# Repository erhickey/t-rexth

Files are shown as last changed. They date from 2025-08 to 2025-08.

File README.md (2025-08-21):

<p align="center">
  t-rexth-logo
</p>

# Thyranathaurus Rexth

Several versions of a split keyboard I created using [Ergogen](https://github.com/ergogen/ergogen).

## [T-Rexth 36 Wired](./t-rexth-36-wired)

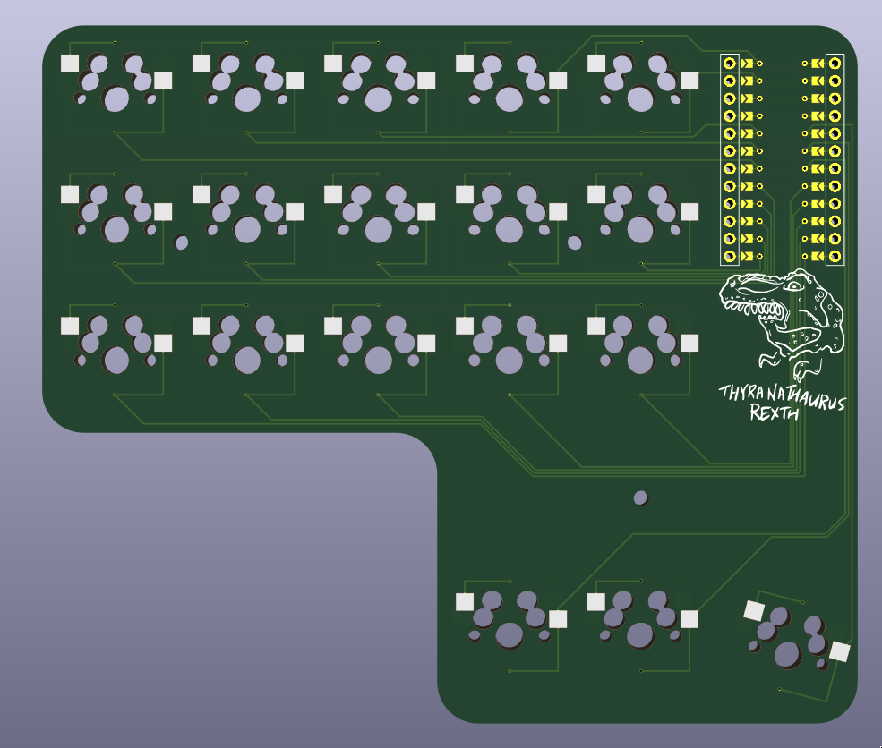
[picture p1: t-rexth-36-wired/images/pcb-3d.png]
t-rexth-36


- 36 keys
- Split keyboard
- Ortholinear
- Wired
- MX switch compatible
- Hot swap sockets

## [T-Rexth 36](./t-rexth-36)

t-rexth-36

- 36 keys
- Split keyboard
- Ortholinear w/columnar stagger
- Wireless
- MX switch compatible
- Hot swap sockets
- Tenting puck compatible

## [T-Rexth 30](./t-rexth-30)

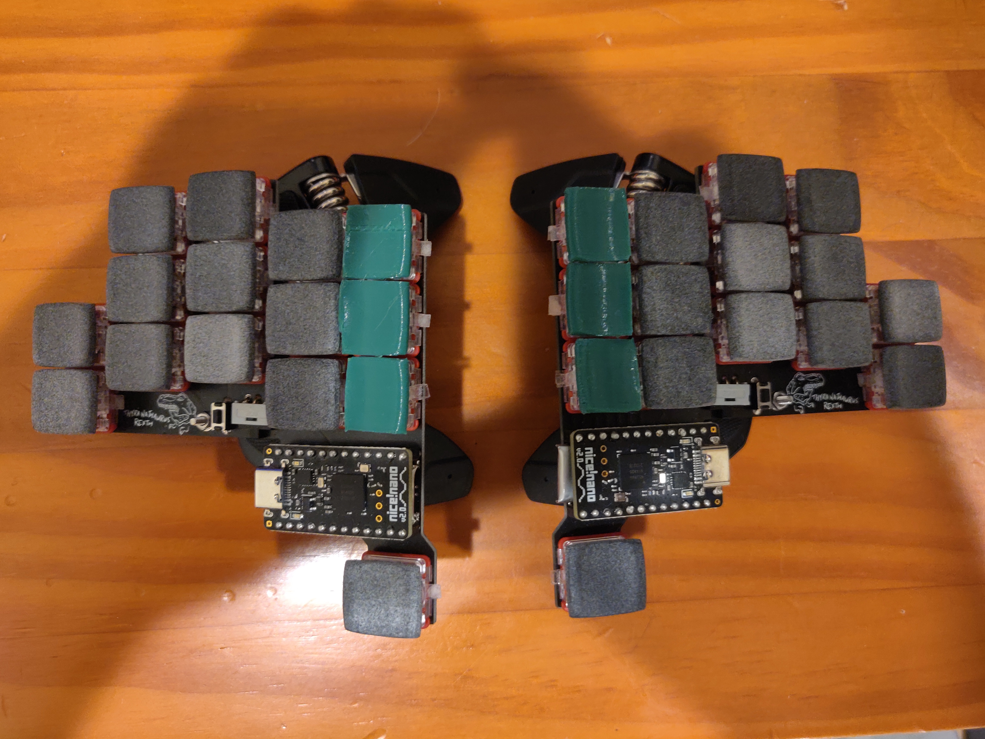
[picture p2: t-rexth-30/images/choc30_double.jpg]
t-rexth-36


- 30 keys
- Split keyboard
- Ortholinear w/columnar stagger
- Wireless
- Choc switch compatible
- Minimal spacing
- Tenting puck compatible

# Credits/Thanks

- Created with [Ergogen](https://github.com/ergogen/ergogen) by [MrZealot](https://zealot.hu/)
- Motivated by [Ben Vallack's videos](https://www.youtube.com/channel/UC4NNPgQ9sOkBjw6GlkgCylg)
- [Guide](https://flatfootfox.com/ergogen-introduction/) by [FlatFootFox](https://flatfootfox.com/)
- Lots of help from members of [Ergogen Discord](https://discord.gg/nbKcAZB)
- Artwork by [Perce](https://madebyperce.com)
- Keycaps by [Pseudoku](https://github.com/pseudoku/PseudoMakeMeKeyCapProfiles)
- Tenting Puck by [lacohe](https://www.thingiverse.com/thing:5336898)

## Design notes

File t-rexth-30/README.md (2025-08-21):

# Thyranathaurus Rexth 30

t-rexth-36

## Notes

This was my first attempt at building a custom keyboard, and has a couple issues:

- Attempting to solder battery wires onto the PCB without shorting your battery can be tricky.
- The spacing between the innermost columns is not wide enough, thus the philadelphia minimalist keycaps [do not fit both columns](./images/choc30_single.jpg).

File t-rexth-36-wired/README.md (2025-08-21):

# Thyranathaurus Rexth

Under construction

## Firmware

[Example zmk configuration](https://github.com/erhickey/keyboards/tree/main/)

## Notes

Uses [infused-kim's](https://github.com/infused-kim) [reversible nice!nano footprint](https://github.com/infused-kim/kb_ergogen_fp/).

## Parts

In addition to the parts below a JST SH 4 pin cable and hotswap sockets are required.

| Type | Part | Details |
|---|---|---|
| Controller | [Adafruit KB2040 - RP2040 Kee Boar Driver](https://octopart.com/search?q=kb2040&currency=USD&specs=0) | [Adafruit](https://learn.adafruit.com/adafruit-kb2040) |
| Machine Pin Sockets | [Mill-Max 801 INTERCONNECT MACHINED PIN SOCKET](https://octopart.com/search?q=801-47-012-10-012000&currency=USD&specs=0) | [Mill-Max](https://www.mill-max.com/products/socket/801-xx-xxx-10-012000) |
| Socket Pins | [Mill-Max 3330 Straight Pin](https://octopart.com/search?q=3330-0-00-15-00-00-03-0&currency=USD&specs=0) | [Mill-Max](https://www.mill-max.com/products/pin/3330) |
| M2x8 Screws | [M2x8 Socket Hex Pan Head Screw](https://www.amazon.com/YXQ-Socket-Machine-Threaded-Knurled/dp/B01EZPNXZO?th=1) | Part Number: MT0502-004 - 3.8mm Head Diameter 2mm Head Height |
| M2 Threaded Insert | [M2 Female Thread Brass Threaded Insert](https://www.amazon.com/dp/B07LBQFNQD?th=1) | 3mm Length x 3.2mm OD |

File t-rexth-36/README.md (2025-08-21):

# Thyranathaurus Rexth 36

t-rexth-36

## Notes

PCB track width and spacing is 0.15mm. Make sure your manufacturer is capable of printing boards with those specs. I used [JLCPCB](https://jlcpcb.com/capabilities/pcb-capabilities).

## Parts

| Type | Part | Manufacturer |
|---|---|---|
| Tactile Button | [C&K PTS636 SP43 LFS](https://www.mouser.com/ProductDetail/CK/PTS636-SP43-LFS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) | [C&K Switches](https://www.ckswitches.com/media/2779/pts636.pdf) |
| Slide Switch | [EAO 09.10290.01](https://www.mouser.com/ProductDetail/EAO/091029001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) | [EAO](https://eao.com) |
| Machine Pin Sockets | [Mill-Max 801 INTERCONNECT MACHINED PIN SOCKET](https://www.mouser.com/ProductDetail/Mill-Max/801-47-012-10-012000?qs=5aG0NVq1C4x40xNvDlnKzg%3D%3D) | [Mill-Max](https://www.mill-max.com/products/socket/801-xx-xxx-10-012000) |
| Socket Pins | [Mill-Max 3330 Straight Pin](https://www.mouser.com/ProductDetail/Mill-Max/3330-0-00-15-00-00-03-0?qs=s8Nb1z4Wn%2FSwJBcI97lmUw%3D%3D) | [Mill-Max](https://www.mill-max.com/products/pin/3330) |
| JST PH 2.0 Connector | [TE 1775469-2](https://www.mouser.com/ProductDetail/TE-Connectivity/1775469-2?qs=fvVej%2FMj3jdYOde%252BssG5lg%3D%3D) | [TE Connectivity](https://www.te.com/usa-en/product-1775469-2.html) |

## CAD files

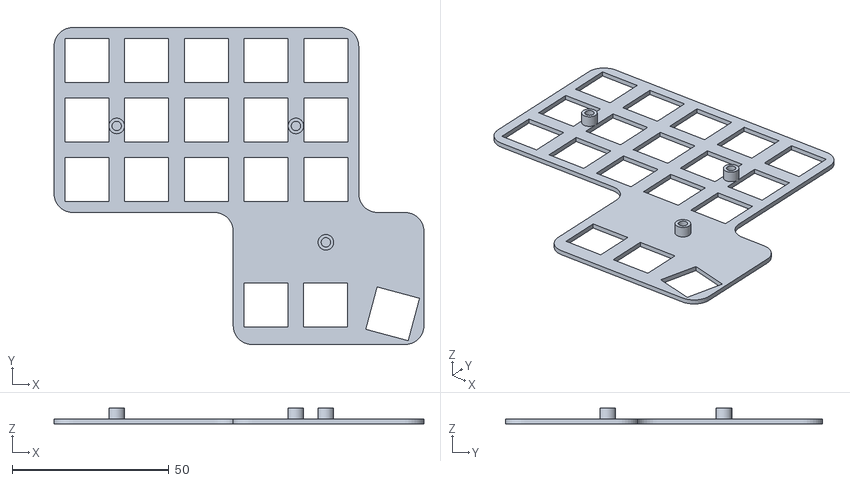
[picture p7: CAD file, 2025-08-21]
t-rexth-36-wired/case/plate_right.stl
118.0 x 101.1 x 5.00

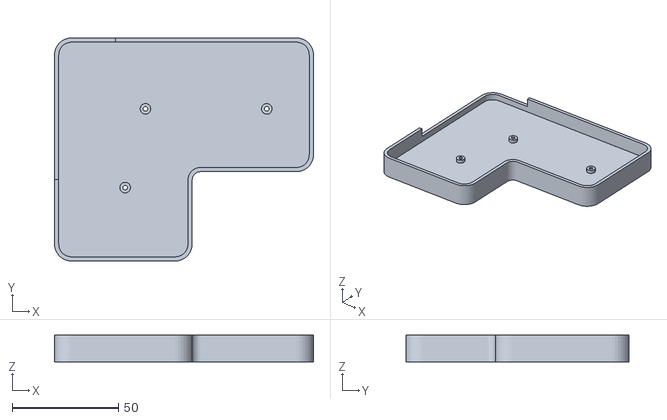
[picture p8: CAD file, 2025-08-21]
t-rexth-36-wired/case/bottom_right.stl
122.0 x 105.1 x 12.6

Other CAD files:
t-rexth-36-wired/case/bottom_left.stl
t-rexth-36-wired/case/plate_left.stl

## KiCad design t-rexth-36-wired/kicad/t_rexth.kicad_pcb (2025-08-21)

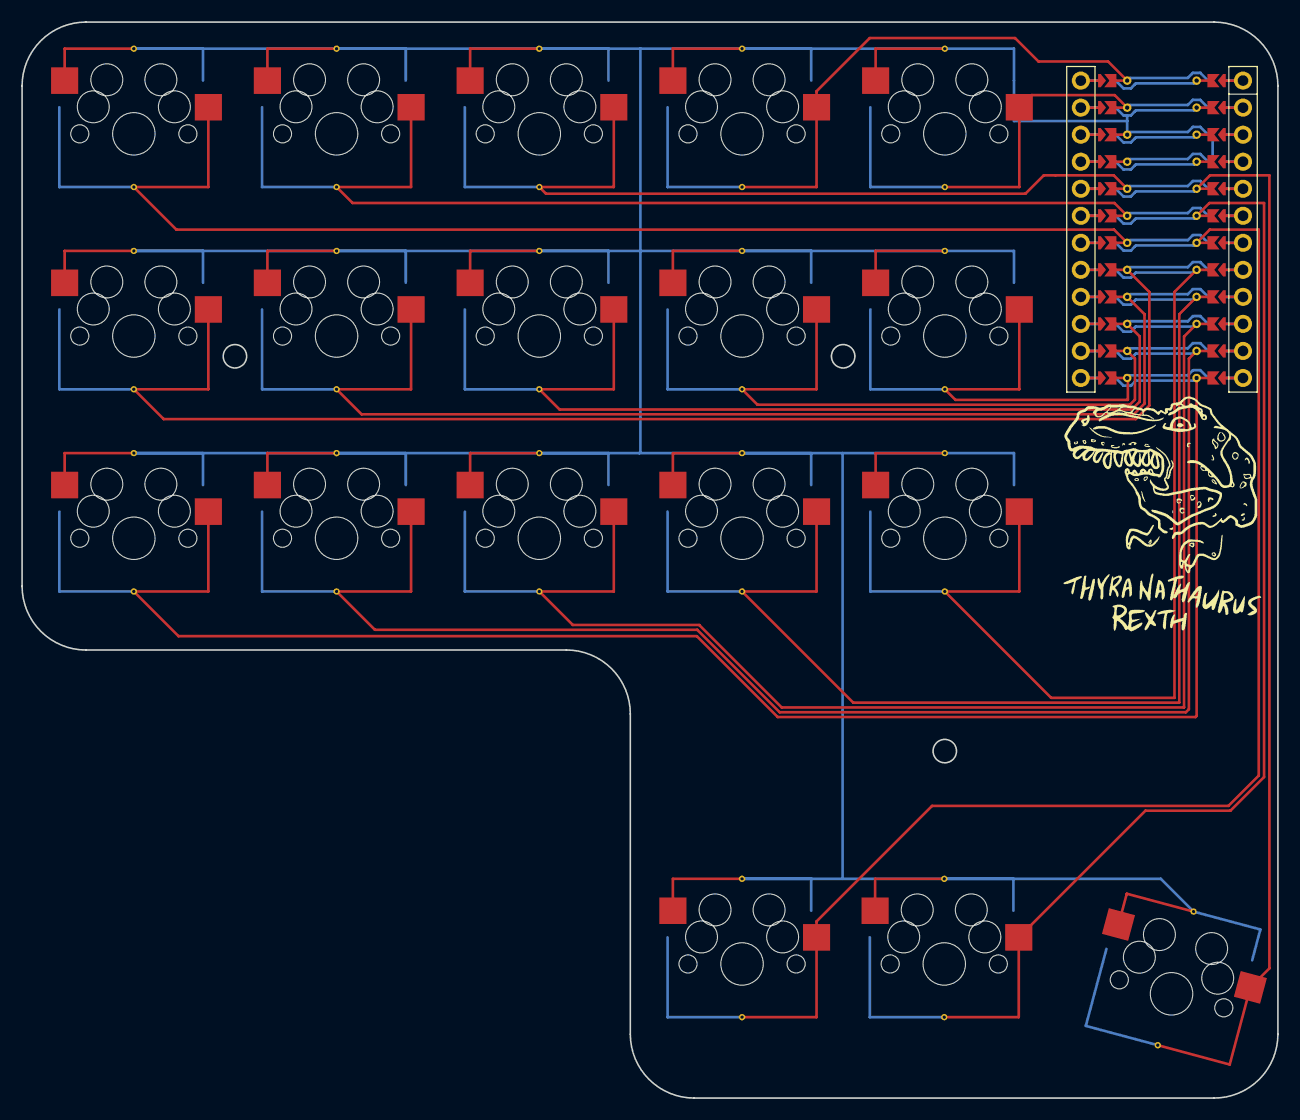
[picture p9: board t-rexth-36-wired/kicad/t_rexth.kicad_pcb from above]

Board: 2 copper layers, 118.0 x 101.1 mm, 19 parts (0 on the bottom side), 19 nets.

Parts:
MCU1: nice_nano
S1, S2, S3, S4, S5, S6, S7, S8, S9, S10, S11, S12, S13, S14, S15, S16, S17, S18: MX_direct_reversible_hotswap

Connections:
GND: MCU1.2, MCU1.121, MCU1.122, S1.1, S1.2, S2.1, S2.2, S3.1, S3.2, S4.1, S4.2, S5.1, S5.2, S6.1, S6.2, S7.1, S7.2, S8.1, S8.2, S9.1, S9.2, S10.1, S10.2, S11.1, S11.2, S12.1, S12.2, S13.1, S13.2, S14.1, S14.2, S15.1, S15.2, S16.1, S16.2, S17.1, S17.2, S18.1, S18.2
P0: MCU1.123, S15.1
P1: MCU1.124, S12.1
P2: MCU1.120, S9.1
P3: MCU1.119, S6.1
P4: MCU1.118, S3.1
P5: MCU1.117, S2.1
P6: MCU1.116, S5.1
P7: MCU1.115, S8.1
P8: MCU1.114, S11.1
P9: MCU1.113, S14.1
P10: MCU1.12, S1.1
P14: MCU1.10, S7.1
P15: MCU1.9, S10.1
P16: MCU1.11, S4.1
P18: MCU1.8, S13.1
P19: MCU1.7, S16.1
P20: MCU1.6, S17.1
P21: MCU1.5, S18.1

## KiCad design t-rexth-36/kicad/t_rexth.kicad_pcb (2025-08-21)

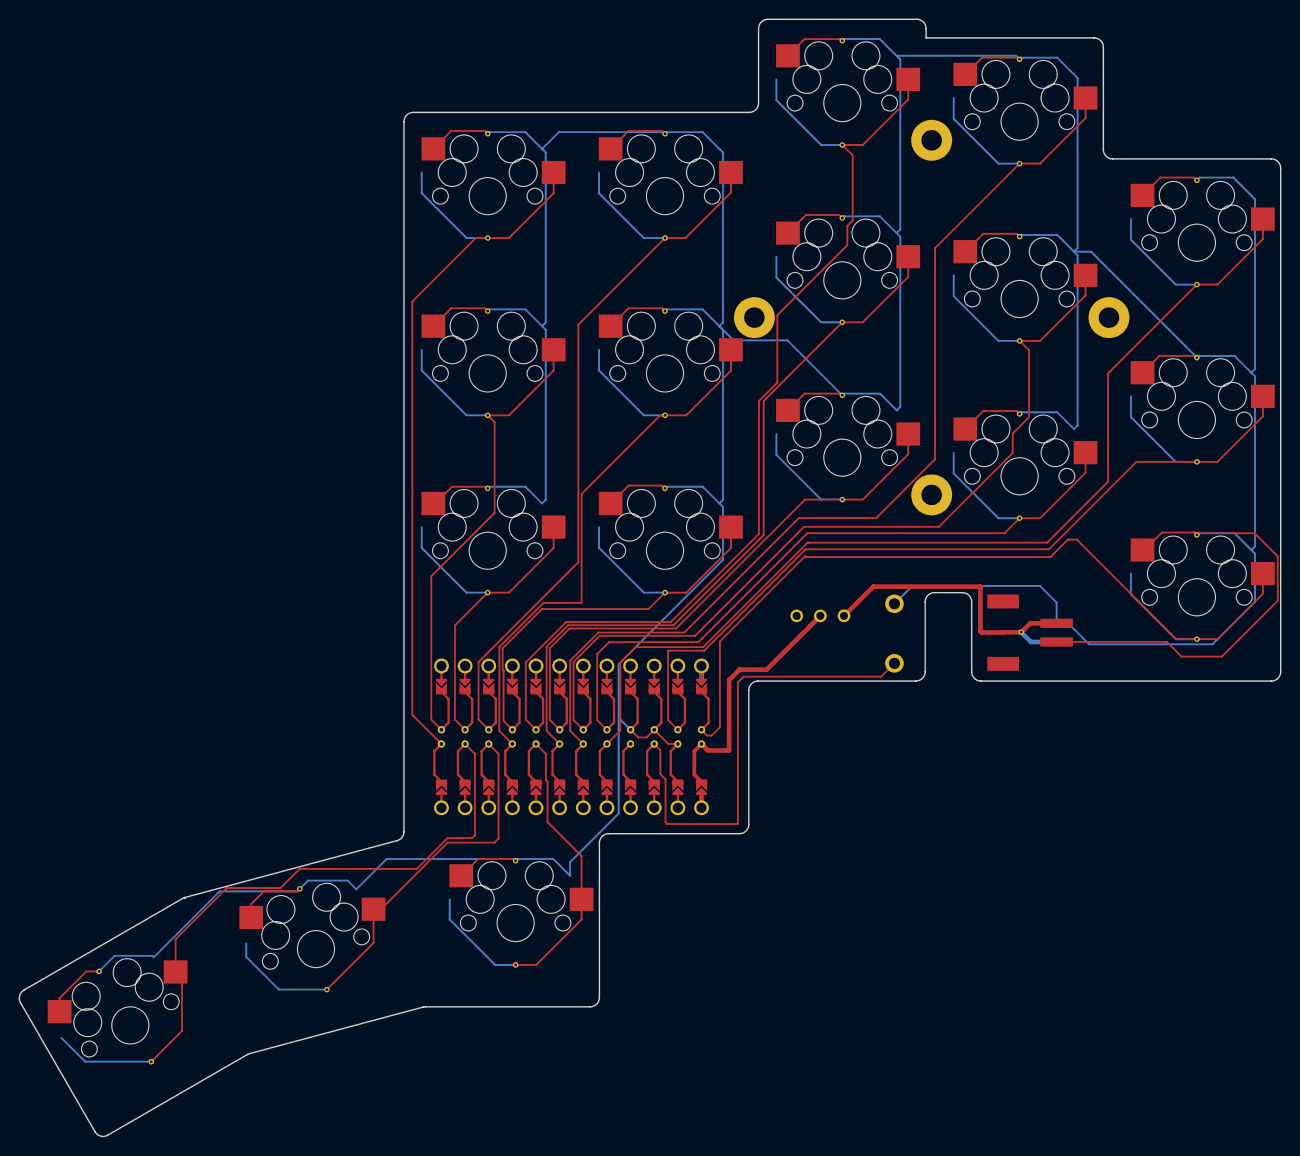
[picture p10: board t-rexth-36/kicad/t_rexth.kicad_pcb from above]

Board: 2 copper layers, 135.5 x 120.0 mm, 23 parts (0 on the bottom side), 22 nets.

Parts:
B1: RST; PTS636
JST_PH_SMD1: 17754692
MCU1: ProMicro
S1, S2, S3, S4, S5, S6, S7, S8, S9, S10, S11, S12, S13, S14, S15, S16, S17, S18: MX
T1: SWITCH_09-10290_EOZ
_2: Tenting Puck

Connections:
BATT: JST_PH_SMD1.1, JST_PH_SMD1.2, T1.2
GND: B1.1, JST_PH_SMD1.1, JST_PH_SMD1.2, MCU1.2, MCU1.21, MCU1.22, S1.1, S1.2, S2.1, S2.2, S3.1, S3.2, S4.1, S4.2, S5.1, S5.2, S6.1, S6.2, S7.1, S7.2, S8.1, S8.2, S9.1, S9.2, S10.1, S10.2, S11.1, S11.2, S12.1, S12.2, S13.1, S13.2, S14.1, S14.2, S15.1, S15.2, S16.1, S16.2, S17.1, S17.2, S18.1, S18.2
P0: MCU1.23, S14.1
P1: MCU1.24, S13.1
P2: MCU1.20, S10.1
P3: MCU1.19, S11.1
P4: MCU1.18, S7.1
P5: MCU1.17, S9.1
P6: MCU1.16, S4.1
P7: MCU1.15, S6.1
P8: MCU1.14, S1.1
P9: MCU1.13, S2.1
P10: MCU1.12, S3.1
P14: MCU1.10, S17.1
P15: MCU1.9, S5.1
P16: MCU1.11, S18.1
P18: MCU1.8, S16.1
P19: MCU1.7, S8.1
P20: MCU1.6, S12.1
P21: MCU1.5, S15.1
RAW: MCU1.1, T1.1
RST: B1.2, MCU1.3

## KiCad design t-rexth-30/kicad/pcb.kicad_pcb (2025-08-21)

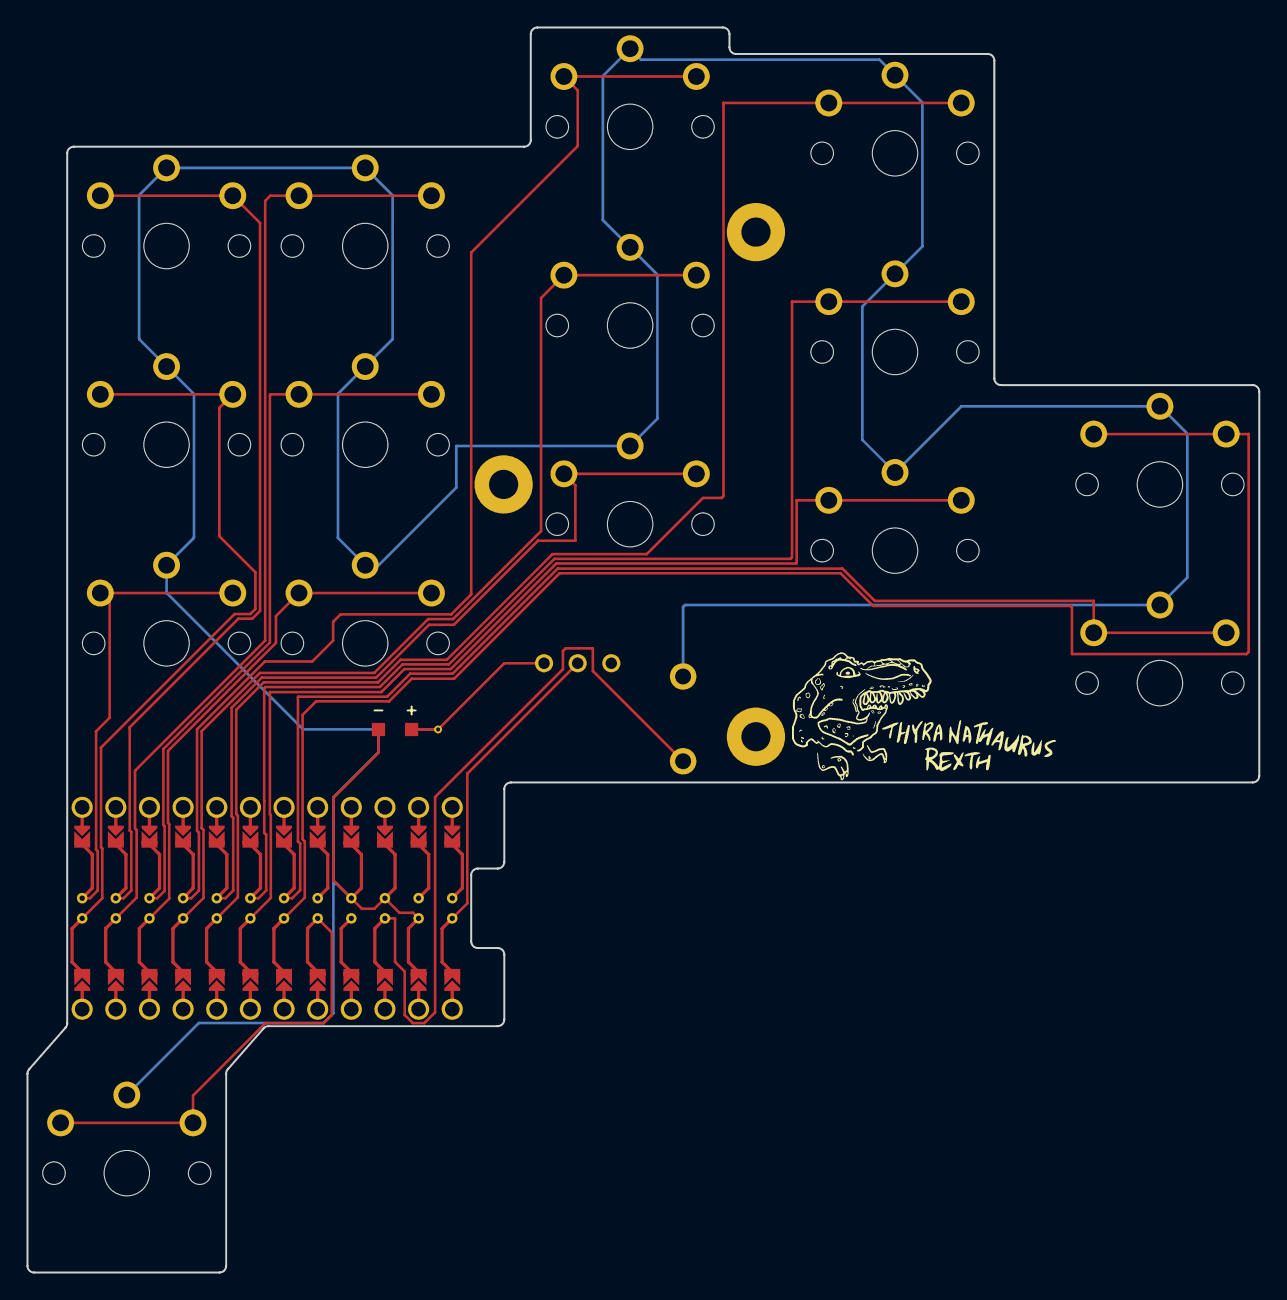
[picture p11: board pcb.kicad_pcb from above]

Board: 2 copper layers, 93.0 x 94.0 mm, 21 parts (0 on the bottom side), 19 nets.

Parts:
B1: RST; PTS636
MCU1: ProMicro
PAD1, PAD2: SMDPad
S1, S2, S3, S4, S5, S6, S7, S8, S9, S10, S11, S12, S13, S14, S15: PG1350
T1: SWITCH_09-10290_EOZ
_2: Tenting Puck

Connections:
BATT: PAD1.1, T1.3
GND: B1.1, MCU1.2, MCU1.21, MCU1.22, PAD2.1, S1.2, S2.2, S3.2, S4.2, S5.2, S6.2, S7.2, S8.2, S9.2, S10.2, S11.2, S12.2, S13.2, S14.2, S15.2
P3: MCU1.19, S13.1
P4: MCU1.18, S11.1
P5: MCU1.17, S7.1
P6: MCU1.16, S9.1
P7: MCU1.15, S5.1
P8: MCU1.14, S3.1
P9: MCU1.13, S1.1
P10: MCU1.12, S2.1
P14: MCU1.10, S4.1
P15: MCU1.9, S8.1
P16: MCU1.11, S6.1
P18: MCU1.8, S12.1
P19: MCU1.7, S10.1
P20: MCU1.6, S14.1
P21: MCU1.5, S15.1
RAW: MCU1.1, T1.1
RST: B1.2, MCU1.3

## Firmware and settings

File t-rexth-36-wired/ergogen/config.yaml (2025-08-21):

meta:
  engine: 4.1.0

units:
  kx: u
  ky: u

  column_spread: U

  thumb_offset: 40
  right_thumb_shift_x: 3
  right_thumb_shift_y: -2.1

  plate_hole_width: 14
  plate_hole_height: 14

  controller_width: 17.8
  controller_length: 35
  controller_padding_left: 2
  controller_padding_right: 1
  controller_space: controller_width + controller_padding_left + controller_padding_right

  outline_fillet: 6
  outline_coefficient: 0.5
  outline_padding: 1
  outline_left: (-outline_coefficient kx) - outline_padding
  outline_right: (outline_coefficient kx) + outline_padding
  outline_top: (outline_coefficient ky) + outline_padding
  outline_bottom: (-outline_coefficient ky) - outline_padding

  hotswap_socket_height_actual: 1.85
  hotswap_socket_height: 2

  m2_screw_diameter: 2
  m2_screw_head_diameter: 3.8
  m2_screw_head_height: 2
  screw_hole_radius: 0.5 (1.1 m2_screw_diameter)
  screw_head_radius: 0.5 (m2_screw_head_diameter + 0.7)
  screw_head_height: m2_screw_head_height + 0.5

  threaded_insert_height: 3
  threaded_insert_radius: 1.5
  standoff_radius: threaded_insert_radius + 1

  plate_thickness: 1.5
  pcb_thickness: 1.6
  pcb_top_to_plate_top: 5
  case_wall_thickness: 2
  case_bottom_thickness_minus_screw_head_height: 1.5
  case_bottom_thickness: screw_head_height + case_bottom_thickness_minus_screw_head_height
  case_wall_height: case_bottom_thickness + hotswap_socket_height + pcb_thickness + pcb_top_to_plate_top
  case_wall_height_minus_plate: case_wall_height - pcb_top_to_plate_top

  screw_length: case_bottom_thickness_minus_screw_head_height + hotswap_socket_height + pcb_thickness + pcb_top_to_plate_top - plate_thickness

tl_screw: &top_left_screw
  what: circle
  where:
    ref: [fingers_pinky_home]
    shift: [0.5kx, -0.1ky]
tm_screw: &top_right_screw
  what: circle
  where:
    ref: [fingers_index_home]
    shift: [0.5kx, -0.1ky]
br_screw: &bottom_right_screw
  what: circle
  where:
    ref: [fingers_inner_bottom]
    shift: [0, -0.5thumb_offset]

points:
  mirror: 115
  zones:
    fingers:
      anchor.shift: [140, -160] # place in kicad workspace
      key.spread: column_spread
      columns:
        pinky:
          rows:
            bottom.net_from: P10
            home.net_from: P5
            top.net_from: P4
        ring:
          rows:
            bottom.net_from: P16
            home.net_from: P6
            top.net_from: P3
        middle:
          rows:
            bottom.net_from: P14
            home.net_from: P7
            top.net_from: P2
        index:
          rows:
            bottom.net_from: P15
            home.net_from: P8
            top.net_from: P1
        inner:
          rows:
            bottom.net_from: P18
            home.net_from: P9
            top.net_from: P0

    thumbs:
      anchor:
        ref: fingers_index_bottom
        shift: [0, -thumb_offset]
      columns:
        left:
          rows.thumb.net_from: P19
        center:
          rows.thumb.net_from: P20
        right:
          rows.thumb.net_from: P21
          key:
            splay: -15
            shift: [right_thumb_shift_x, right_thumb_shift_y]

outlines:
  keys:
    - what: rectangle
      where: true
      bound: false
      size: [kx - 0.05, ky - 0.05]
  board:
    - what: polygon
      operation: stack
      fillet: outline_fillet
      points:
        - ref: fingers_pinky_top
          shift: [outline_left, outline_top]
        - ref: fingers_inner_top
          shift: [outline_right + controller_space, outline_top]
        - ref: fingers_inner_bottom
          shift: [outline_right + controller_space, outline_bottom - thumb_offset + right_thumb_shift_y]
        - ref: fingers_index_bottom
          shift: [outline_left, outline_bottom - thumb_offset + right_thumb_shift_y]
        - ref: fingers_index_bottom
          shift: [outline_left, outline_bottom]
        - ref: fingers_pinky_bottom
          shift: [outline_left, outline_bottom]
  board_and_keys:
    - name: board
    - operation: subtract
      name: keys

  board_mirror:
    - what: polygon
      operation: stack
      fillet: outline_fillet
      points:
        - ref: mirror_fingers_pinky_top
          shift: [outline_left, outline_top]
        - ref: mirror_fingers_inner_top
          shift: [outline_right + controller_space, outline_top]
        - ref: mirror_fingers_inner_bottom
          shift: [outline_right + controller_space, outline_bottom - thumb_offset + right_thumb_shift_y]
        - ref: mirror_fingers_index_bottom
          shift: [outline_left, outline_bottom - thumb_offset + right_thumb_shift_y]
        - ref: mirror_fingers_index_bottom
          shift: [outline_left, outline_bottom]
        - ref: mirror_fingers_pinky_bottom
          shift: [outline_left, outline_bottom]
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
